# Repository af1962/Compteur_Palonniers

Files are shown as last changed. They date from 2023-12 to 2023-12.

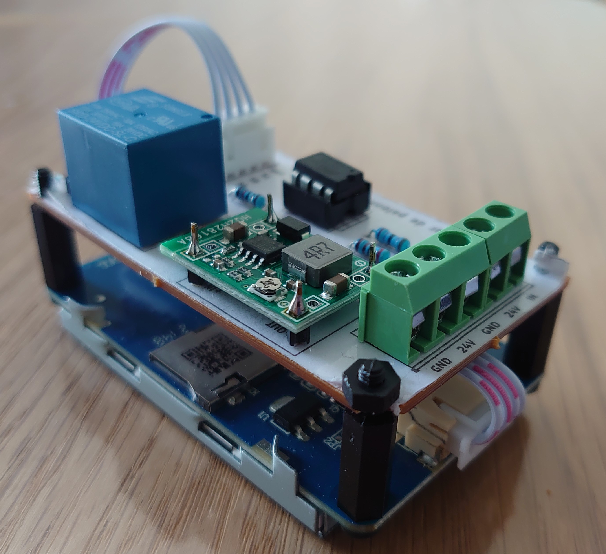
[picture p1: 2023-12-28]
Photos/Assemblage.JPG

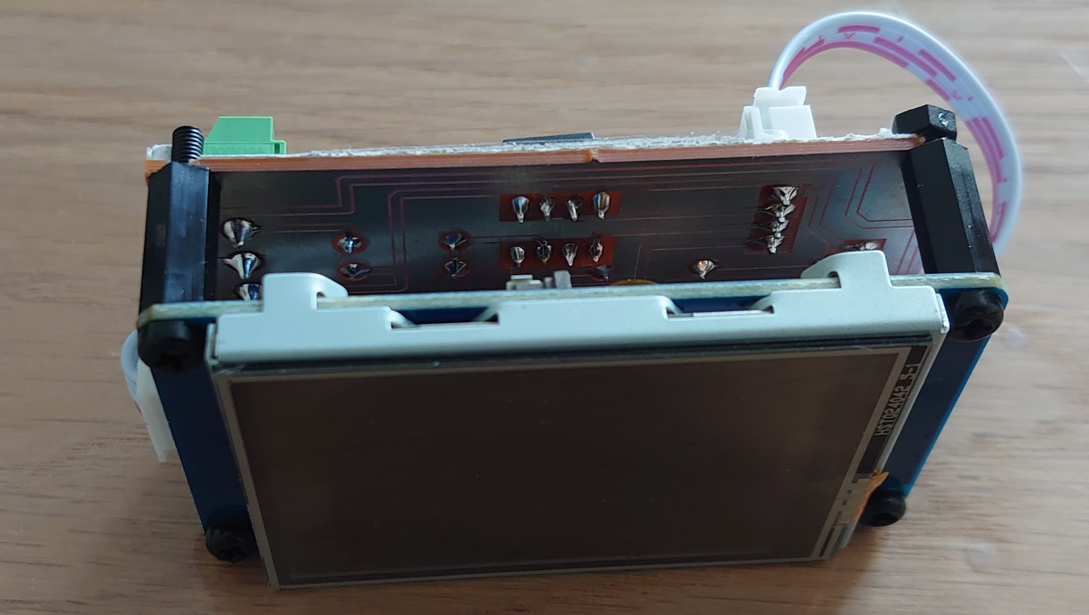
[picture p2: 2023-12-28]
Photos/Assemblage_1.JPG

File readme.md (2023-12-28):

Le montage qui est présenté içi est un compteur de passage de pièces. Il s'agit de la seconde version (la 1er était à base d'un atmega328).
Réalisé avec Kicad pour la partie soft et à l'aide d'une CNC pour la gravure à l'anglaise du PCB.
La version finale mise en production comporte une fonction d'auto extinction automatique.
L'automaintien est confié à un relais qui coupe l'alimention après le temps prédéfini.
Il existe aussi une version avec mémorisation du dernier comptage. Le problème étant lié à la durée de vie de la mémoire EEPROM. Dans les conditions de production actuelle (environ 250 pièces par jour) la durée de vie est d'environ 400 jours.
Il faudrait un algorithme qui modifie l'emplacement mémoire de la sauvegarde, après un certain nombre de comptage.

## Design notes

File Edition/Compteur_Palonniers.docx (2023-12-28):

2023

Compteur de palonniers

OPTIONS AUTO-EXTINCTION

Farid ADDA

#include <SoftwareSerial.h>

#include <simpleBouton.h>

#include "Heures.h"

SoftwareSerial Serial(0,4); // RX ,TX

#define automaintien 1

simpleBouton capteur(2); // bouton en broche D2 Cablage : pin---BP---GND

Heures heures;

unsigned long previousTime=0;

unsigned long currentTime=0; // Temps millis() en cours

int minuterie = 0; // Temps de fonctionnement

int duree =3600; // Temps de réarmement de la minuterie

int compteur=0; // Compteur

String str=""; // Lecture du port série

void setup()

{

Serial.begin(9600);

Serial.setTimeout(100);

pinMode(automaintien,OUTPUT);

minuterie=duree;

digitalWrite(automaintien,HIGH);

}

void loop()

{

str=Serial.readString();

// Raz en appuyant sur l'écran

if(str=="raz")

{

compteur=0;

Serial.print("cpt.val=");

Serial.print(compteur);

ValideNextion();

}

// Capteur comptage

capteur.actualiser();

if(capteur.vientDEtreEnfonce()&& millis()>2000) // Evite l'incrémentation à la mise sous tension

{

compteur++;

Serial.print("cpt.val=");

Serial.print(compteur);

ValideNextion();

minuterie= duree ; // Relance la minuterie à chaque passage

}

// Décomptage et test minuterie

currentTime=millis();

if((currentTime-previousTime)>1000)

{

previousTime=currentTime;

String decompte = "tps.txt=\"" + heures.Affiche(minuterie)+"\"";

Serial.print(decompte);

ValideNextion();

minuterie--;

}

if(minuterie<=0 || str=="off")

{

digitalWrite(automaintien,LOW); // Coupe l'alimentation

}

}

// Validation Nextion

void ValideNextion()

{

Serial.write(0xFF);

Serial.write(0xFF);

Serial.write(0xFF);

}

Bibliothèque

Heure.h

#include "Arduino.h"

class Heures

{

private:

uint8_t minutes;

uint8_t secondes;

char minSec[5];

public:

String Affiche(int temps);

};

Heure.cpp

#include "Heures.h"

String Heures::Affiche(int temps)

{

minutes = temps / 60;

secondes = temps % 60;

sprintf(minSec, "%0.2d:%0.2d", minutes, secondes);

return String (minSec);

}

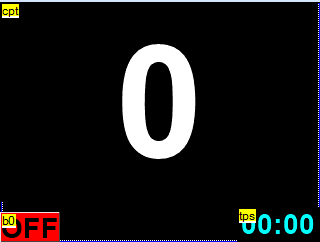
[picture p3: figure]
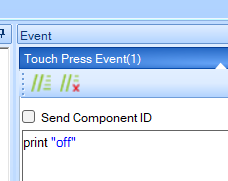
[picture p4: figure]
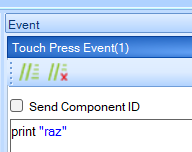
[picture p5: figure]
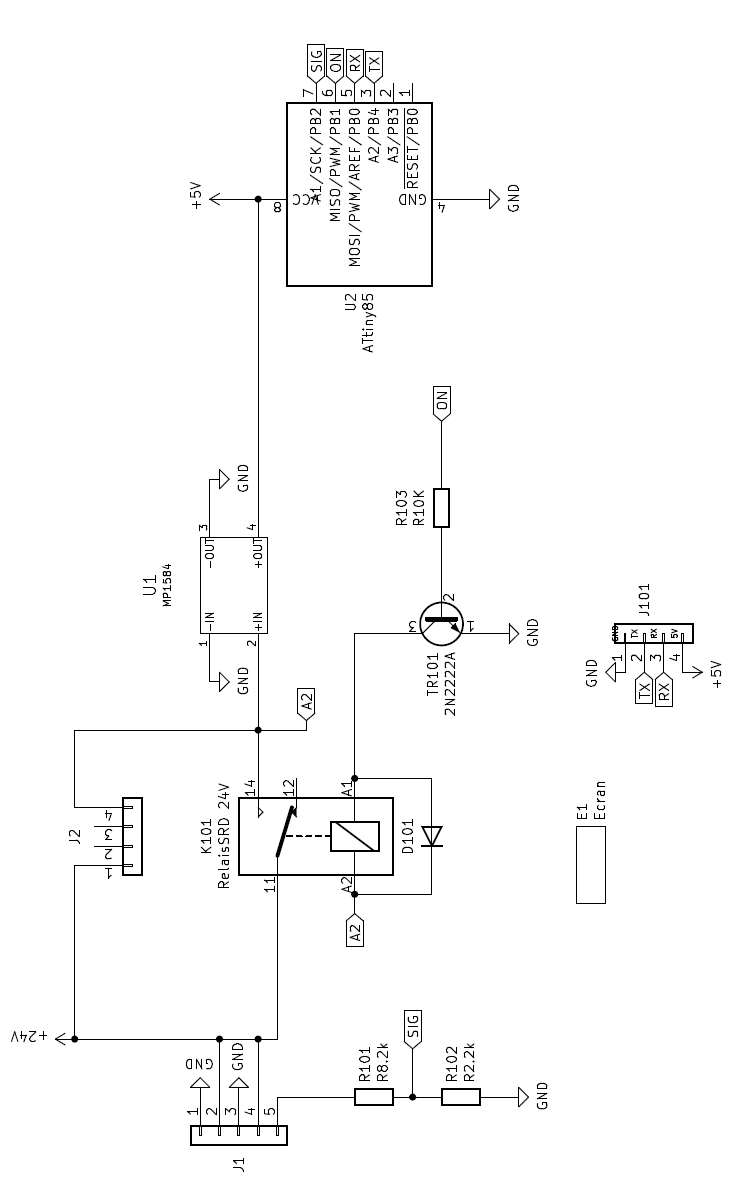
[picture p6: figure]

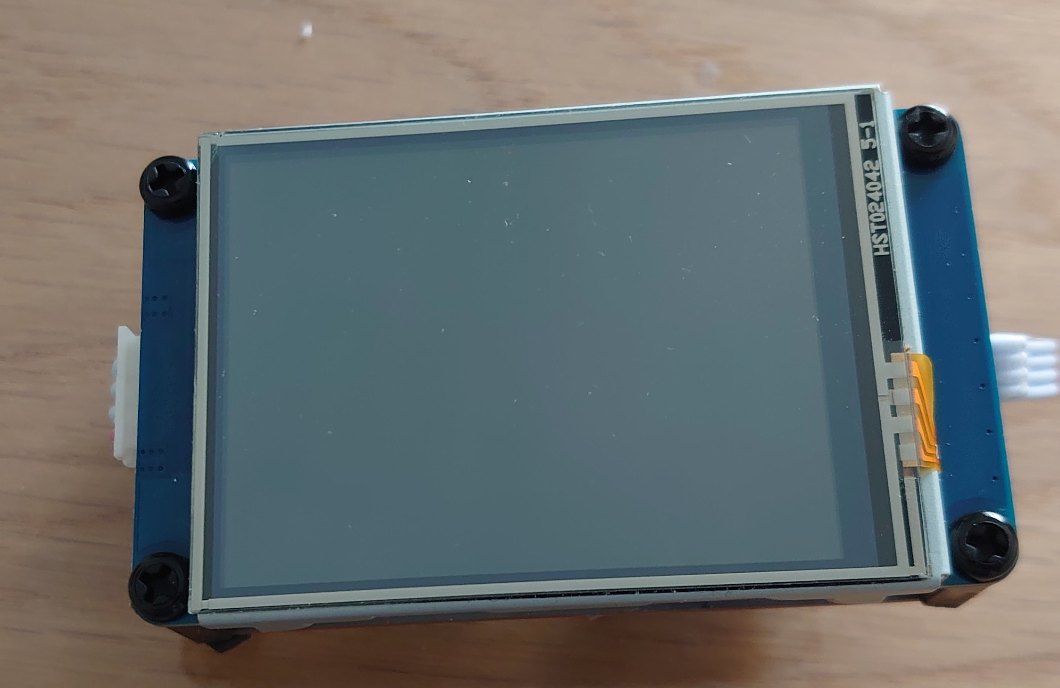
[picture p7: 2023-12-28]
Photos/Ecran.JPG

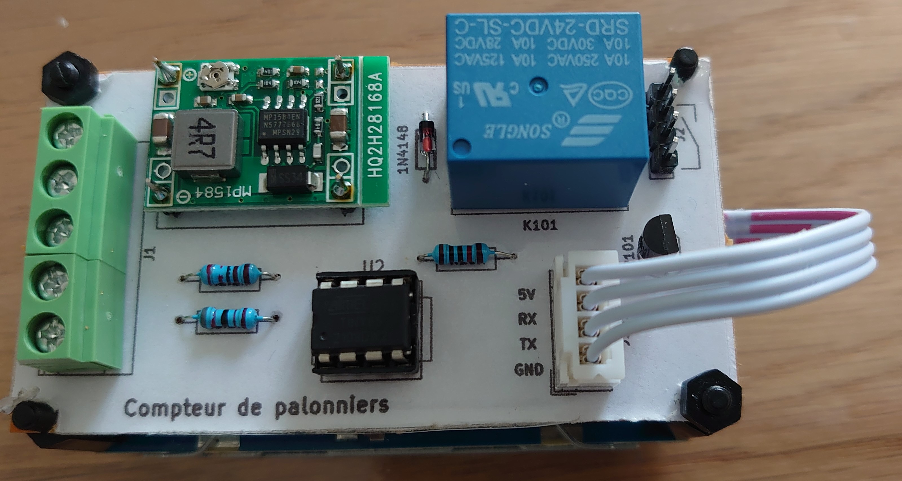
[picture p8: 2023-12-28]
Photos/Coté composants.JPG

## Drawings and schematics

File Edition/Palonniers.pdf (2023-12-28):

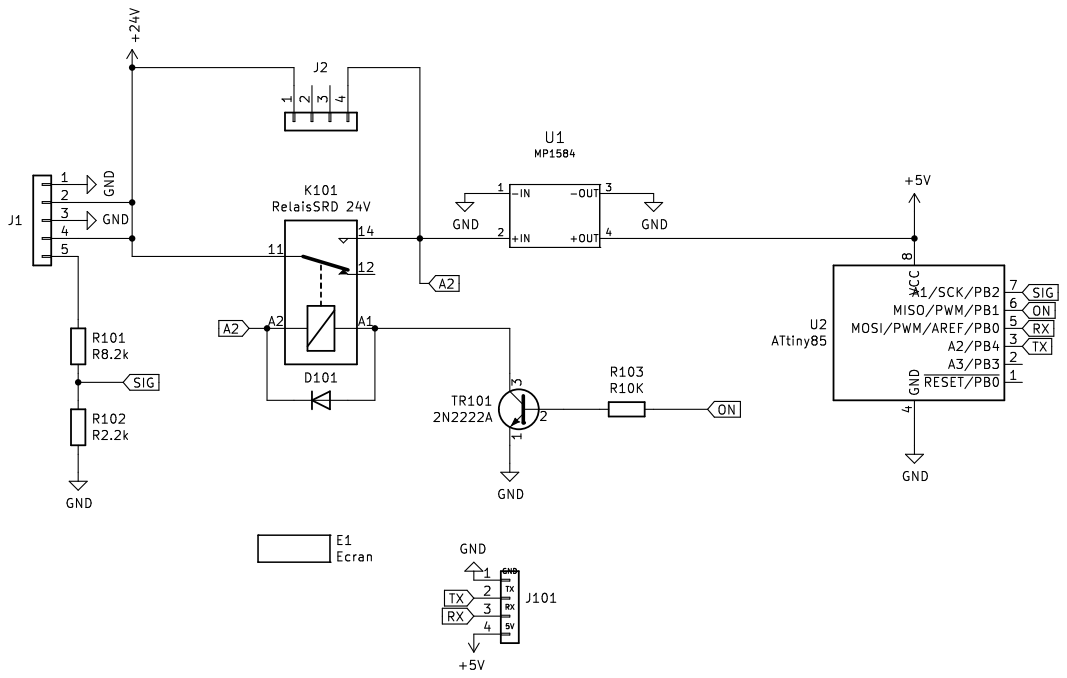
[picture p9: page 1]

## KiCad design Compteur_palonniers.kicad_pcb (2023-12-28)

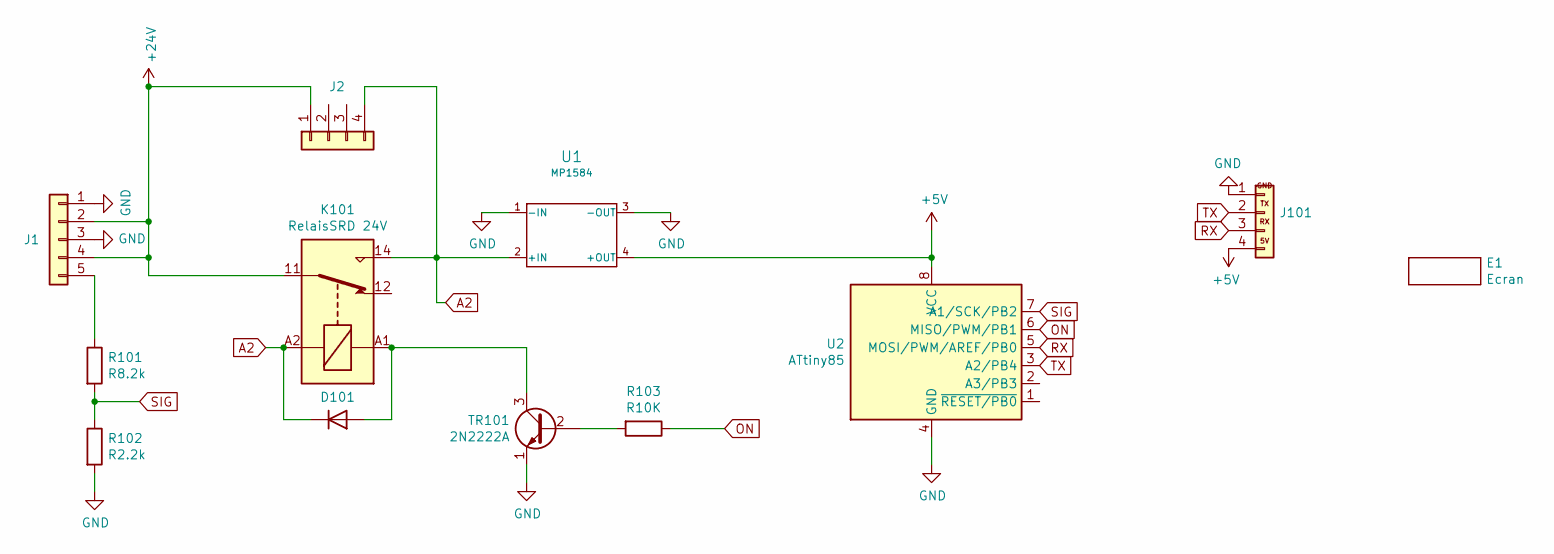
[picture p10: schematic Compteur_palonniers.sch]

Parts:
D101: Diode_1N4148; diode_do35
E1: Ecran; Nextion_24
J1: Conn_01x05; TerminalBlock_Phoenix_MKDS-1,5-5-5.08_1x05_P5.08mm_Horizont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
J2: Conn_01x04; pin_strip_4
J101: Connecteur_Nextion; JST_XH_B04B-XH-A_04x2.50mm_Straight
K101: RelaisSRD 24V; Relais_SRD
R101: R8.2k; R_025W
R102: R2.2k; R_025W
R103: R10K; R_025W
TR101: 2N2222A; TO-92
U1: MP1584
U2: ATtiny85; dil_8-300_socket

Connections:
14: D101.1 (K), J2.4, K101.14, K101.A2, U1.2 (+IN)
+5V: J101.4, U1.4 (+OUT), U2.8 (VCC)
+24V: J1.2, J1.4, J2.1, K101.11
GND: J1.1, J1.3, J101.1, R102.2, TR101.1 (E), U1.1 (-IN), U1.3 (-OUT), U2.4 (GND)
unnamed: D101.2 (A), K101.A1, TR101.3 (C)
unnamed: J1.5, R101.1
unnamed: R103.2, TR101.2 (B)
ON: R103.1, U2.6 (MISO/PWM/PB1)
RX: J101.3, U2.5 (MOSI/PWM/AREF/PB0)
SIG: R101.2, R102.1, U2.7 (A1/SCK/PB2)
TX: J101.2, U2.3 (A2/PB4)

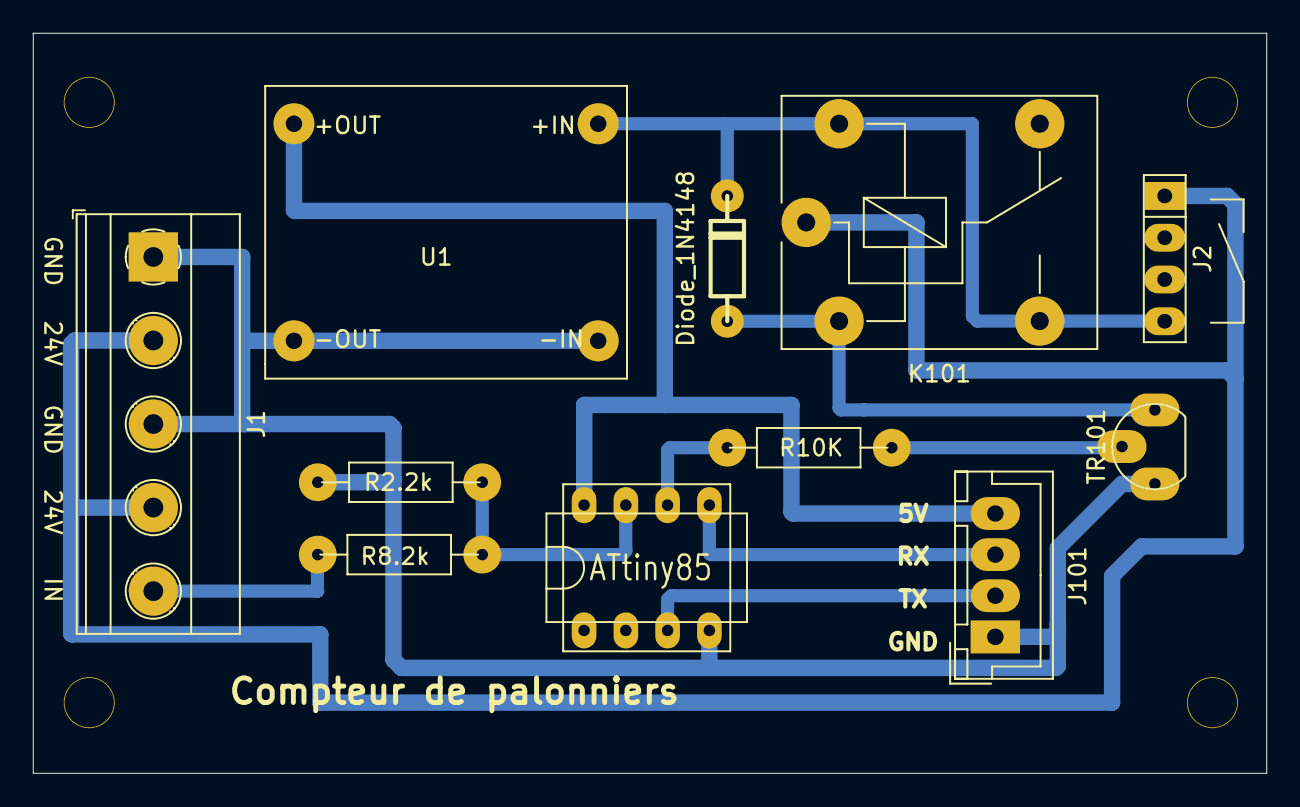
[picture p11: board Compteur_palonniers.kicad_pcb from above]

Board: 2 copper layers, 75.0 x 45.0 mm, 12 parts (1 on the bottom side), 11 nets.
